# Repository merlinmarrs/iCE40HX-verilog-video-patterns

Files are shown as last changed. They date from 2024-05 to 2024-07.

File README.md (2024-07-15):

bechamel_logo_Plan de travail 1

# Video FPGA Dev Board

A Lattice iCE40HX1K-based FPGA developement board for live-playable video experiments.



 

|                          |                          |
:-------------------------:|:-------------------------:
  | IMG_3808-1024x683

# Features :

- 9-key mechanical button interface
- Relatively low-cost, single board design
- HDMI and VGA out
- Reverse polarity and fuse protection

# Minimal BOM :

[Excel BOM Mouser / Digikey ](https://github.com/merlinmarrs/iCE40HX-verilog-video-patterns/tree/main/PCB%20files)

- 9x Mechanical keyboard keys
- 1x FPGA iCE40HX1K-TQ144
- 1x 100MHz clock oscillator
- 1x SRAM 2Mb 256Kx8
- 1x Flash N25Q032A13ESC40F
- 1x USB-C SMD 6 pin connector
- 1x 3.3V reg TLV73333PDBVT 
- 1x 1.2V reg TLV73312PDBVT
- 1x PFET
- 1x Resettable Fuse
- 1x D-SUB 15 connector
- 1x HDMI Connector 
- 50x 0.1µF capacitor 0805
- 50x  10kΩ, 1.8kΩ, 1kΩ, 470Ω, 270Ω, 120Ω resistors 0805
- 5x LEDs 0805
- 2x Dual-row headers

optional extras : (1x Raspberry Pi Zero, 1x Micro SD holder, 2x 10kΩ potentiometers, 1x fast op-amp, 1x 3.5mm audio jack, 1x dual SMD dip switch, 1x SMD pushbutton)

# PCB files

[KiCAD and Eagle PCBs](https://github.com/merlinmarrs/iCE40HX-verilog-video-patterns/tree/main/PCB%20files)

open_source 

# HDL files

[Verilog, Pin constraints, and synthesized binaries ](https://github.com/merlinmarrs/iCE40HX-verilog-video-patterns/tree/main/verilog)

To compile and upload files :

[Yoysis Open-source Toolchain ](https://github.com/YosysHQ/yosys)



[iCEcube2 Toolchain](https://www.latticesemi.com/iCEcube2)



## Acknowledgements

Mike Field <hamster@snap.net.nz> for his minimalDVID_encoder.vhd : A quick and dirty DVI-D implementation

OLIMEX FPGA dev board https://github.com/OLIMEX/iCE40HX1K-EVB/tree/master

ALHAMBRA FPGA https://github.com/FPGAwars/Alhambra-II-FPGA/tree/master

HDL Bits https://hdlbits.01xz.net/wiki/Main_Page

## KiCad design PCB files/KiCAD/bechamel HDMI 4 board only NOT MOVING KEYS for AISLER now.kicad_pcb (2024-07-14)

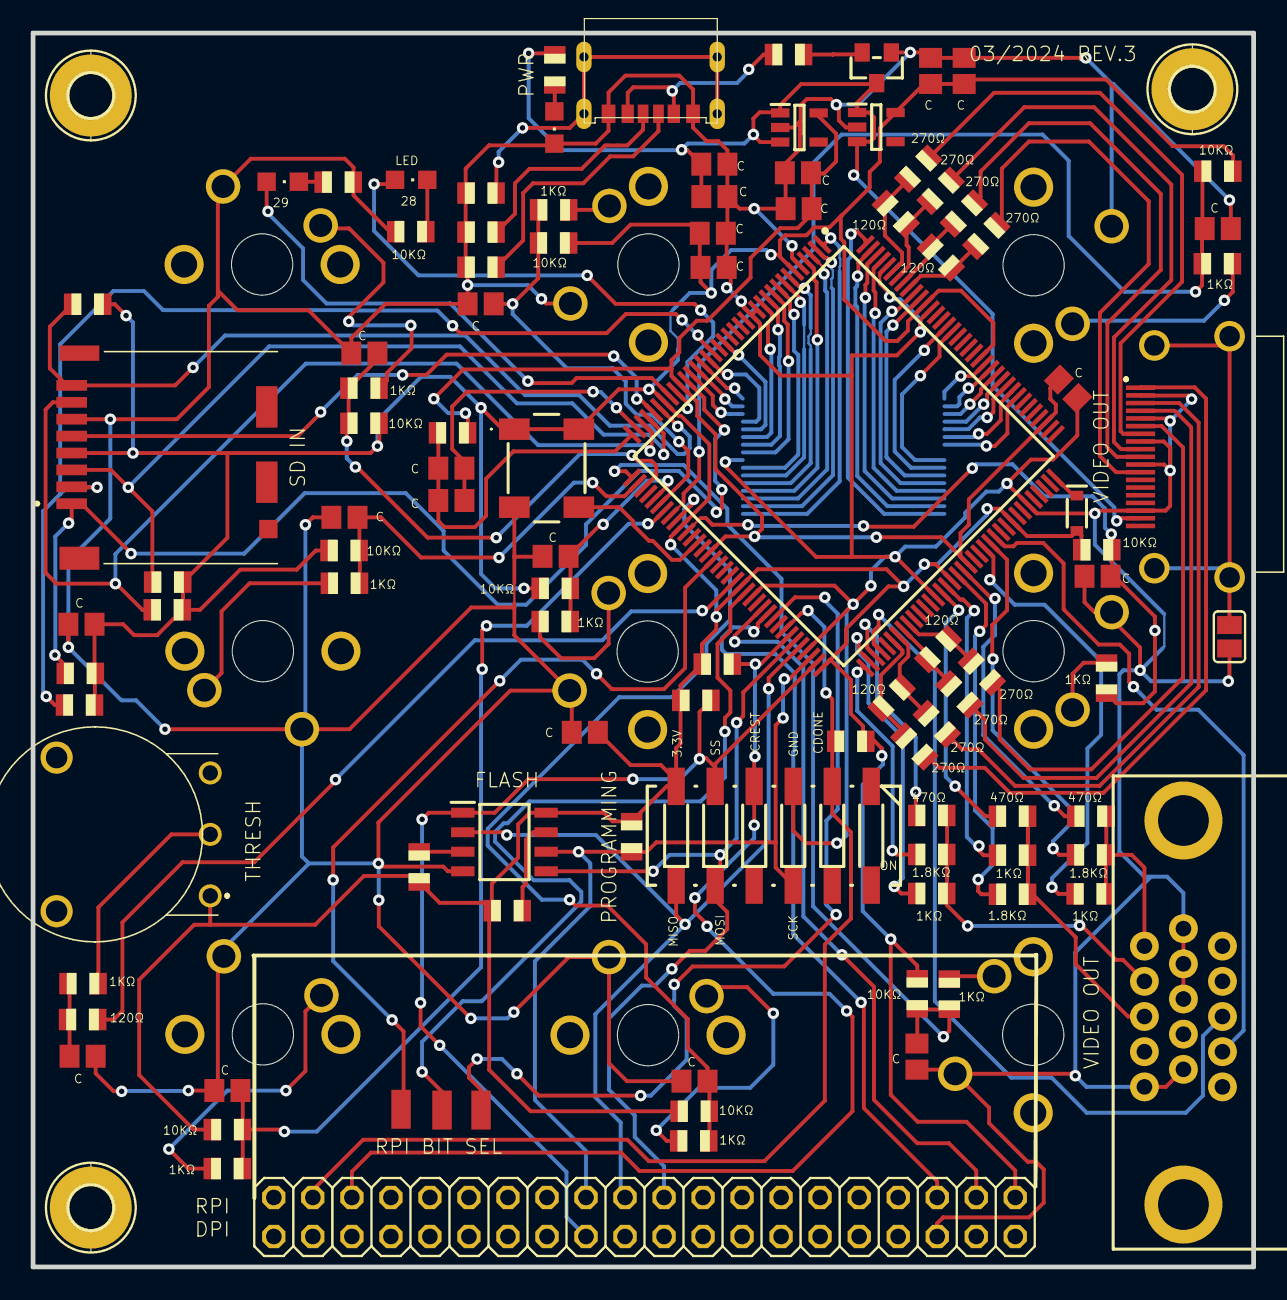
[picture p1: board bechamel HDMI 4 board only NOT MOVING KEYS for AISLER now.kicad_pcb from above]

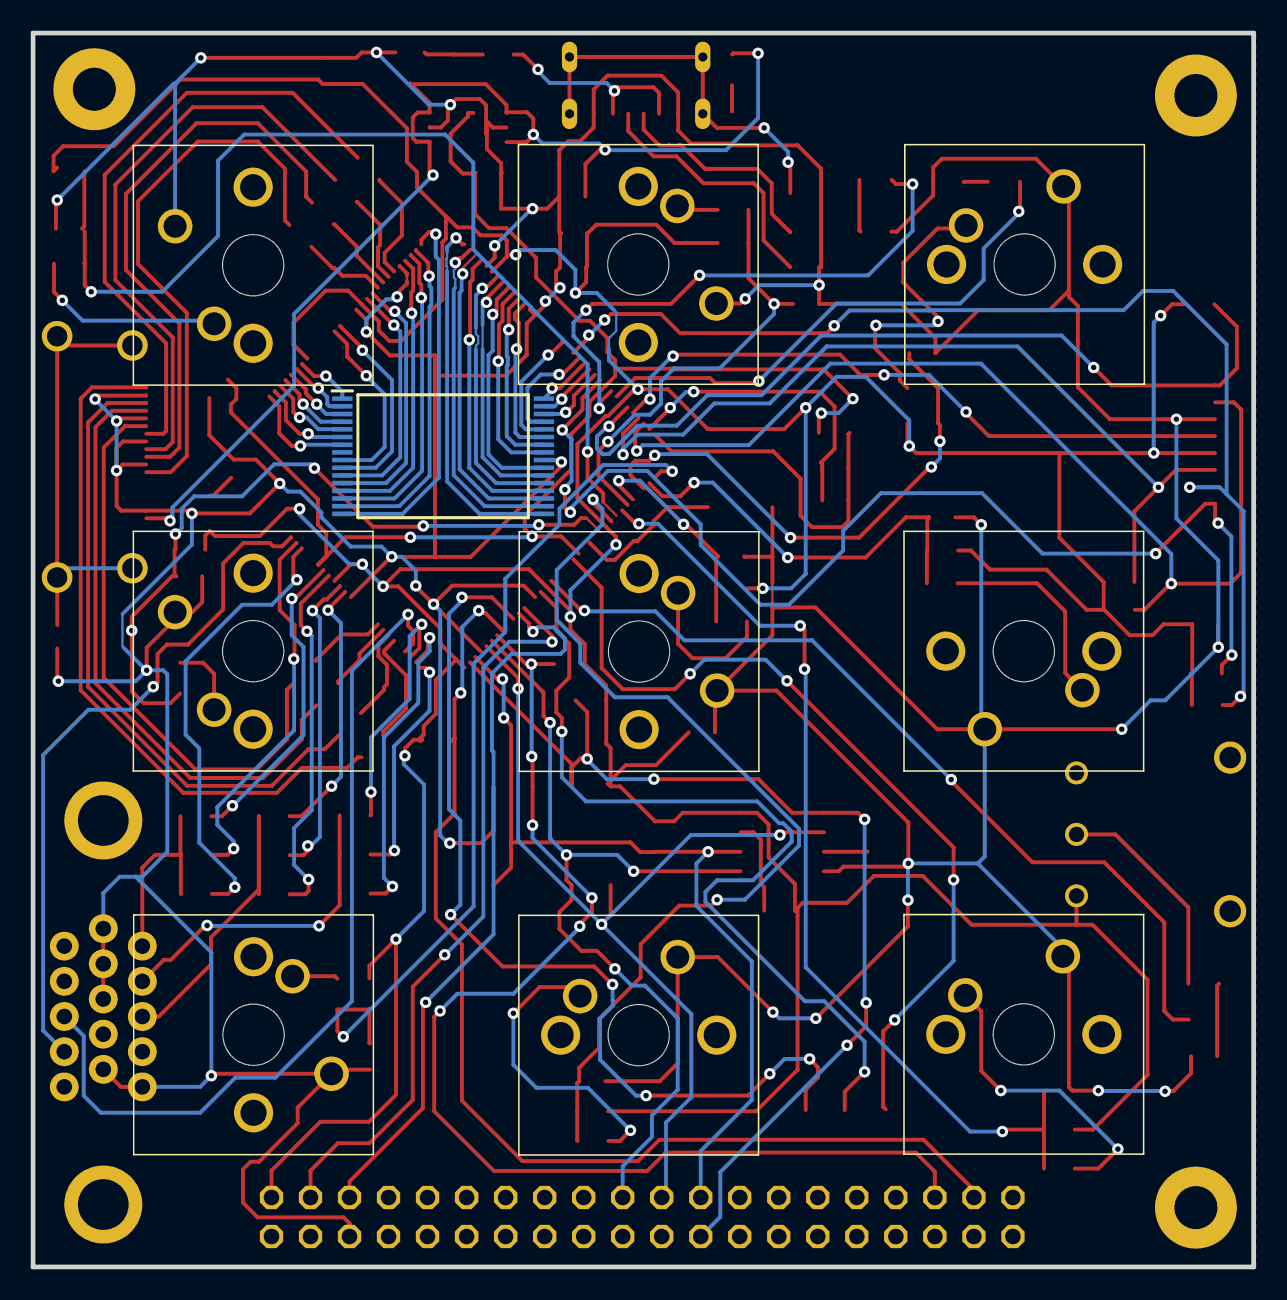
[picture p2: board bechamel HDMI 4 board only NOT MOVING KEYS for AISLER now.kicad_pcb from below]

Board: 2 copper layers, 79.5 x 80.3 mm, 117 parts (10 on the bottom side), 119 nets.

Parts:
C1, C6, C7, C8, C9, C10, C11, C12, C13, C14, C15, C18, C21, C22, C25, C26, C27: 0.1uF; C0805
C3, C4, C5, C16, C23: 10uF; C0805
C17: 5.6nF; C0805
D1: 250mA/100V; SOD-323
FUSE0: FUSE; R0805
H1, H5, H6: MOUNT-PAD-ROUND2.8; 2,8-PAD
IC1: TLV73333PDBVT; SOT95P280X145-5N
IC2: ICE40HX1K-TQ144; QFP50P2200X2200X160-144N
IC3: TLV73312PDBVT; SOT95P280X145-5N
IC4: N25Q032A13ESC40F; SOIC127P600X175-8N
IC6: IS62WV2568BLL-55HLI; SOP50P1340X125-32N
J2: SS-53000-001; SS53000001
J3: DM3CS-SF; DM3CSSF
JP1: 2X20
LED6, LED12, LED13: CHIPLED_0805
P-FET2: SOT23-WIDE
PAD1, PAD2, PAD3: SMD1,27-2,54
R1, R17, R25: 470R; R0805
R2, R5, R7, R15, R18, R22, R24, R26, R47, R49, R51, R53: 1K; R0805
R3, R4, R6, R8, R9, R10, R11, R12, R13, R21, R23, R45, R46, R48, R50, R52, R54, R55, R58, R59: 10K; R0805
R14, R36, R37: 100 ohm; R0805
R16, R20, R27: 1.8K; R0805
R19: 300 ohm; R0805
R28, R29, R31, R32, R34, R35, R39, R40: 270R; R0805
R30, R33, R38, R41: 120R; R0805
R42: 1M; R0805
R43, R44: 5k1; R0805
R56: 1K8 ohm; R0805
R57: 180 ohm; R0805
S1, S2, S3, S4, S5, S6, S7, S8, S13: MX1A-11NW; MX1A11NW
S9: 219-06J; CTS-219-06J
SJ2: SJ
U$1: DB15
U$2: USBC-6P; USCX-06FX-XXMX-01
VR1: RV100F-30-4K1B-B10K-B301; RV100F304K1BB10KB301
Y2: ECS-3953M-080-BN-T-TR; ECS3953M080BNTTR

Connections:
1.2V: C4.1, C26.1, C27.1, IC2.27, IC2.51, IC2.92, IC2.111, IC3.5, R14.2
3.3V: C12.1, C15.1, C16.2, C18.1, C21.1, C25.1, D1.A, IC1.5, IC2.6, IC2.30, IC2.46, IC2.57, IC2.72, IC2.89, IC2.100, IC2.123, IC2.133, IC4.8, J3.4, JP1.1, R3.2, R4.2, R6.2, R8.2, R9.2, R10.2, R11.2, R12.2, R13.2, R21.2, R23.2, R45.2, R46.2, R48.2, R50.2, R52.2, R54.2, R55.1, R58.2, R59.2, S9.6, VR1.1, Y2.1, Y2.4
5V: C3.1, C5.1, IC1.1, IC1.3, IC3.1, IC3.3, J2.18, P-FET2.3, R19.2
5V?: FUSE0.1, P-FET2.2
A0: IC2.4, IC6.20
A1: IC2.3, IC6.19
A2: IC2.2, IC6.18
A3: IC2.1, IC6.17
A4: IC2.144, IC6.16
A5: IC2.143, IC6.15
A6: IC2.142, IC6.14
A7: IC2.141, IC6.13
A8: IC2.120, IC6.3
A9: IC2.121, IC6.2
A10: IC2.24, IC6.31
A11: IC2.122, IC6.1
A12: IC2.135, IC6.12
A13: IC2.119, IC6.4
A14: IC2.134, IC6.11
A15: IC2.116, IC6.7
A16: IC2.129, IC6.10
A17: IC2.128, IC6.9
ADC_IN: IC2.56, R57.2
BLUE: R1.2, R15.2, R16.2, U$1.3
BLUE_1: IC2.87, R1.1
BLUE_2: IC2.88, R15.1
BLUE_3: IC2.90, R16.1
CLK+: IC2.137, R39.2, R41.1
CLK-: IC2.136, R40.2, R41.2
CMD: IC2.33, J3.3, R54.1
CS2: IC2.117, IC6.6
DAT0: IC2.34, J3.7, R55.2
DAT1: IC2.31, J3.8, R59.1
DAT2: IC2.26, J3.1, R45.1
DAT3: IC2.21, J3.2, R58.1
DATA0+: IC2.139, R34.2, R38.1
DATA0-: IC2.138, R35.2, R38.2
DATA1+: IC2.80, R31.2, R33.1
DATA1-: IC2.81, R32.2, R33.2
DATA2+: IC2.78, R28.2, R30.1
DATA2-: IC2.79, R29.2, R30.2
FPGA_CLK: IC2.49, Y2.3
GND: C1.1, C3.2, C4.2, C5.2, C6.1, C7.1, C8.1, C9.1, C10.1, C11.1, C12.2, C13.1, C14.1, C15.2, C16.1, C17.1, C18.2, C21.2, C25.2, C26.2, C27.2, IC1.2, IC2.5, IC2.13, IC2.14, IC2.59, IC2.69, IC2.86, IC2.103, IC2.132, IC2.140, IC3.2, IC4.4, IC6.24, J2.2, J2.5, J2.8, J2.11, J2.17, J3.6, JP1.6, LED6.C, P-FET2.1, R36.1, R37.1, R42.2, R43.2, R44.2, S1.2, S2.2, S3.2, S4.2, S5.2, S6.2, S7.2, S8.2, S9.3, S13.2, SJ2.2, U$1.5, U$1.6, U$1.7, U$1.8, U$1.10, U$2.GND1, U$2.GND2, Y2.2
GREEN: R17.2, R18.2, R20.2, U$1.2
GREEN_1: IC2.75, R17.1
GREEN_2: IC2.74, R18.1
GREEN_3: IC2.73, R20.1
H_SYNC: IC2.76, U$1.13
H_SYNC_IN: IC2.62, JP1.5
I/O0: IC2.7, IC6.21
I/O1: IC2.8, IC6.22
I/O2: IC2.9, IC6.23
I/O3: IC2.10, IC6.25
I/O4: IC2.11, IC6.26
I/O5: IC2.12, IC6.27
I/O6: IC2.19, IC6.28
I/O7: IC2.22, IC6.29
ICE_CDONE: IC2.65, JP1.37, R8.1, S9.2
ICE_CREST: IC2.66, JP1.35, R9.1, S9.4
ICE_MISO: IC2.68, IC4.2, JP1.21, S9.7
ICE_MOSI: IC2.67, IC4.5, JP1.19, S9.8
ICE_SCK: IC2.70, IC4.6, JP1.23, R13.1, S9.10
ICE_SS_B: IC2.71, IC4.1, JP1.24, R12.1, S9.5
KEY_0: C13.2, IC2.37, R50.1, R51.2
KEY_0_LED: IC2.28, LED12.A
KEY_1: C6.2, IC2.38, R3.1, R5.2
KEY_1_LED: IC2.29, LED13.A
KEY_2: C11.2, IC2.39, R48.1, R49.2
KEY_3: C1.2, IC2.41, R2.2, R4.1
KEY_4: C10.2, IC2.42, R46.1, R47.2
KEY_5: C7.2, IC2.43, R6.1, R7.2
KEY_6: C9.2, IC2.44, R23.1, R24.2
KEY_7: C8.2, IC2.45, R21.1, R22.2
KEY_8: C14.2, IC2.47, R52.1, R53.2
unnamed: IC4.7, R10.1
unnamed: LED6.A, R19.1
unnamed: IC4.3, R11.1
unnamed: R43.1, U$2.CC2
unnamed: D1.C, IC2.108
unnamed: C22.2, C23.2, IC2.35
unnamed: C22.1, C23.1, IC2.36, R14.1
unnamed: R42.1, U$2.SHIELD1, U$2.SHIELD2, U$2.SHIELD3, U$2.SHIELD4
unnamed: R56.2, VR1.2
unnamed: J2.1, R28.1
unnamed: R44.1, U$2.CC1
unnamed: J2.MH1, J2.MH2, J2.MH3, J2.MH4, SJ2.1
unnamed: C17.2, R56.1, R57.1
unnamed: J2.3, R29.1
unnamed: J2.4, R31.1
unnamed: LED12.C, R36.2
unnamed: LED13.C, R37.2
unnamed: J2.6, R32.1
unnamed: IC2.52, PAD1.1
unnamed: J2.7, R34.1
unnamed: J2.9, R35.1
unnamed: J2.10, R39.1
unnamed: J2.12, R40.1
unnamed: R2.1, S6.1
unnamed: R5.1, S5.1
unnamed: R7.1, S7.1
unnamed: R22.1, S8.1
unnamed: R24.1, S3.1
unnamed: R47.1, S2.1
unnamed: R49.1, S1.1
unnamed: R51.1, S13.1
unnamed: R53.1, S4.1
unnamed: IC2.58, PAD2.1
unnamed: IC2.63, PAD3.1
PRE_FUSE: FUSE0.2, U$2.VBUS1, U$2.VBUS2
RED: R25.2, R26.2, R27.2, U$1.1
RED_1: IC2.91, R25.1
RED_2: IC2.95, R26.1
RED_3: IC2.96, R27.1
SD_CLK: IC2.32, J3.5
V_SYNC: IC2.97, U$1.14
V_SYNC_IN: IC2.61, JP1.3
~CS1: IC2.25, IC6.30
~OE: IC2.23, IC6.32
~WE: IC2.118, IC6.5

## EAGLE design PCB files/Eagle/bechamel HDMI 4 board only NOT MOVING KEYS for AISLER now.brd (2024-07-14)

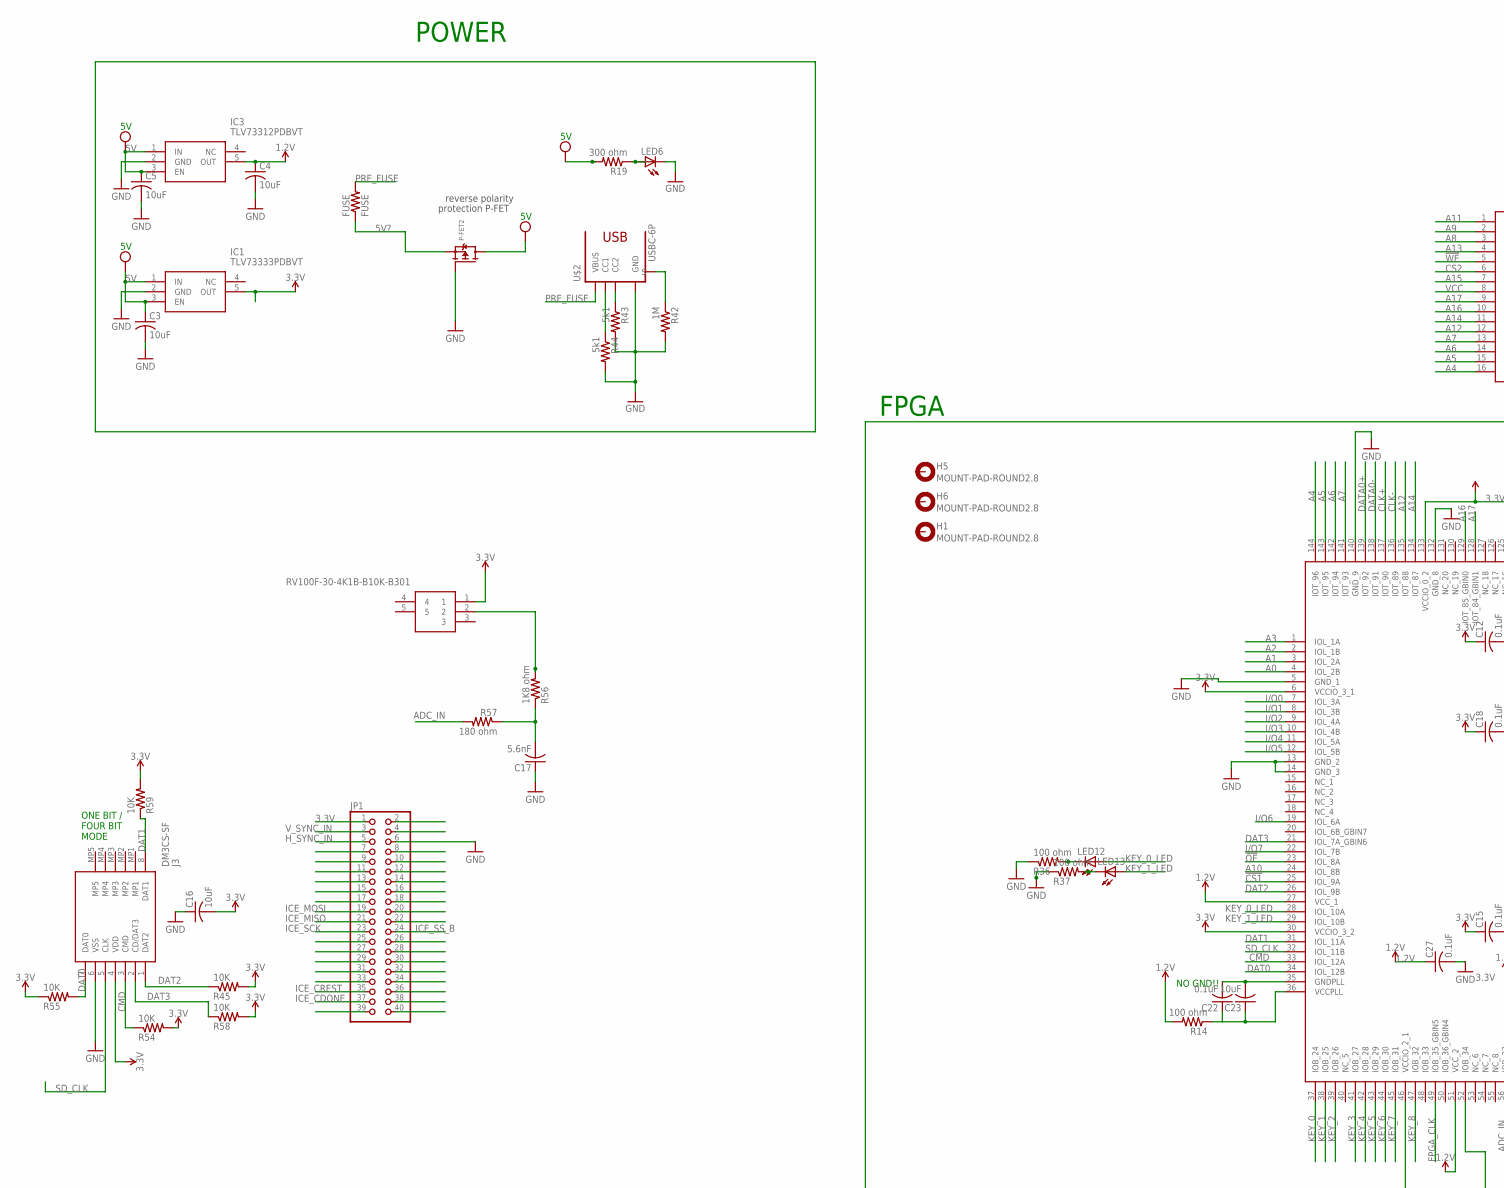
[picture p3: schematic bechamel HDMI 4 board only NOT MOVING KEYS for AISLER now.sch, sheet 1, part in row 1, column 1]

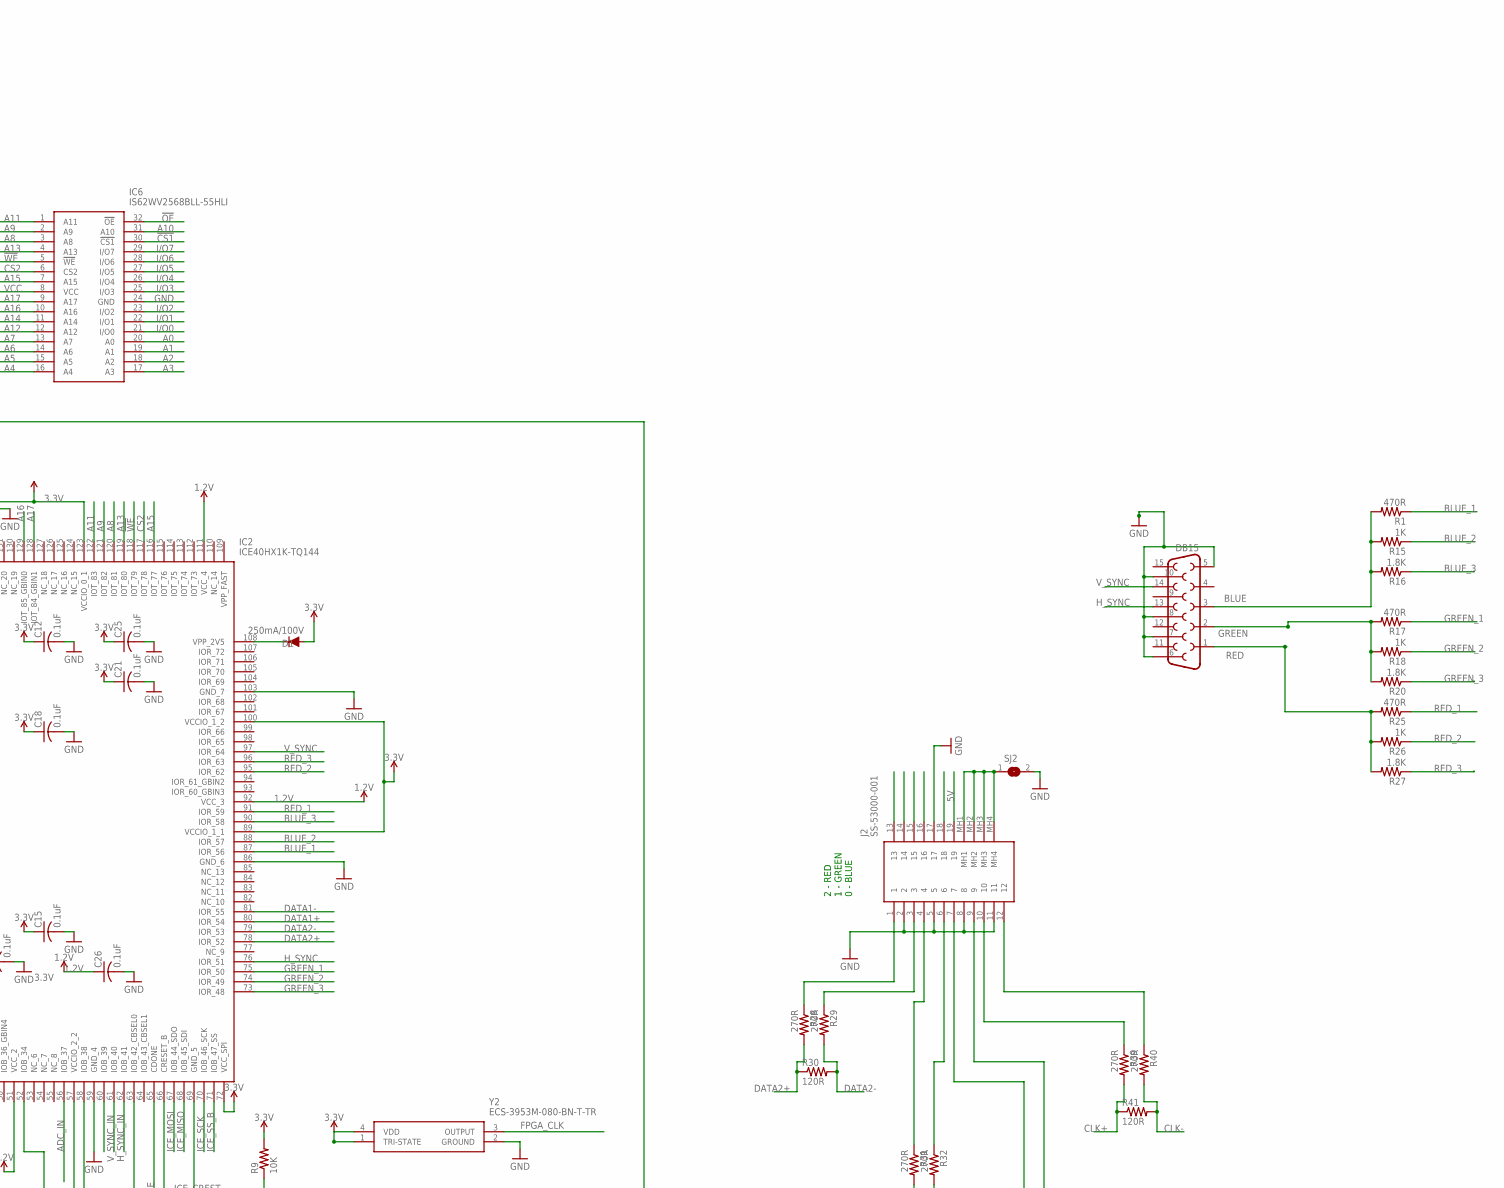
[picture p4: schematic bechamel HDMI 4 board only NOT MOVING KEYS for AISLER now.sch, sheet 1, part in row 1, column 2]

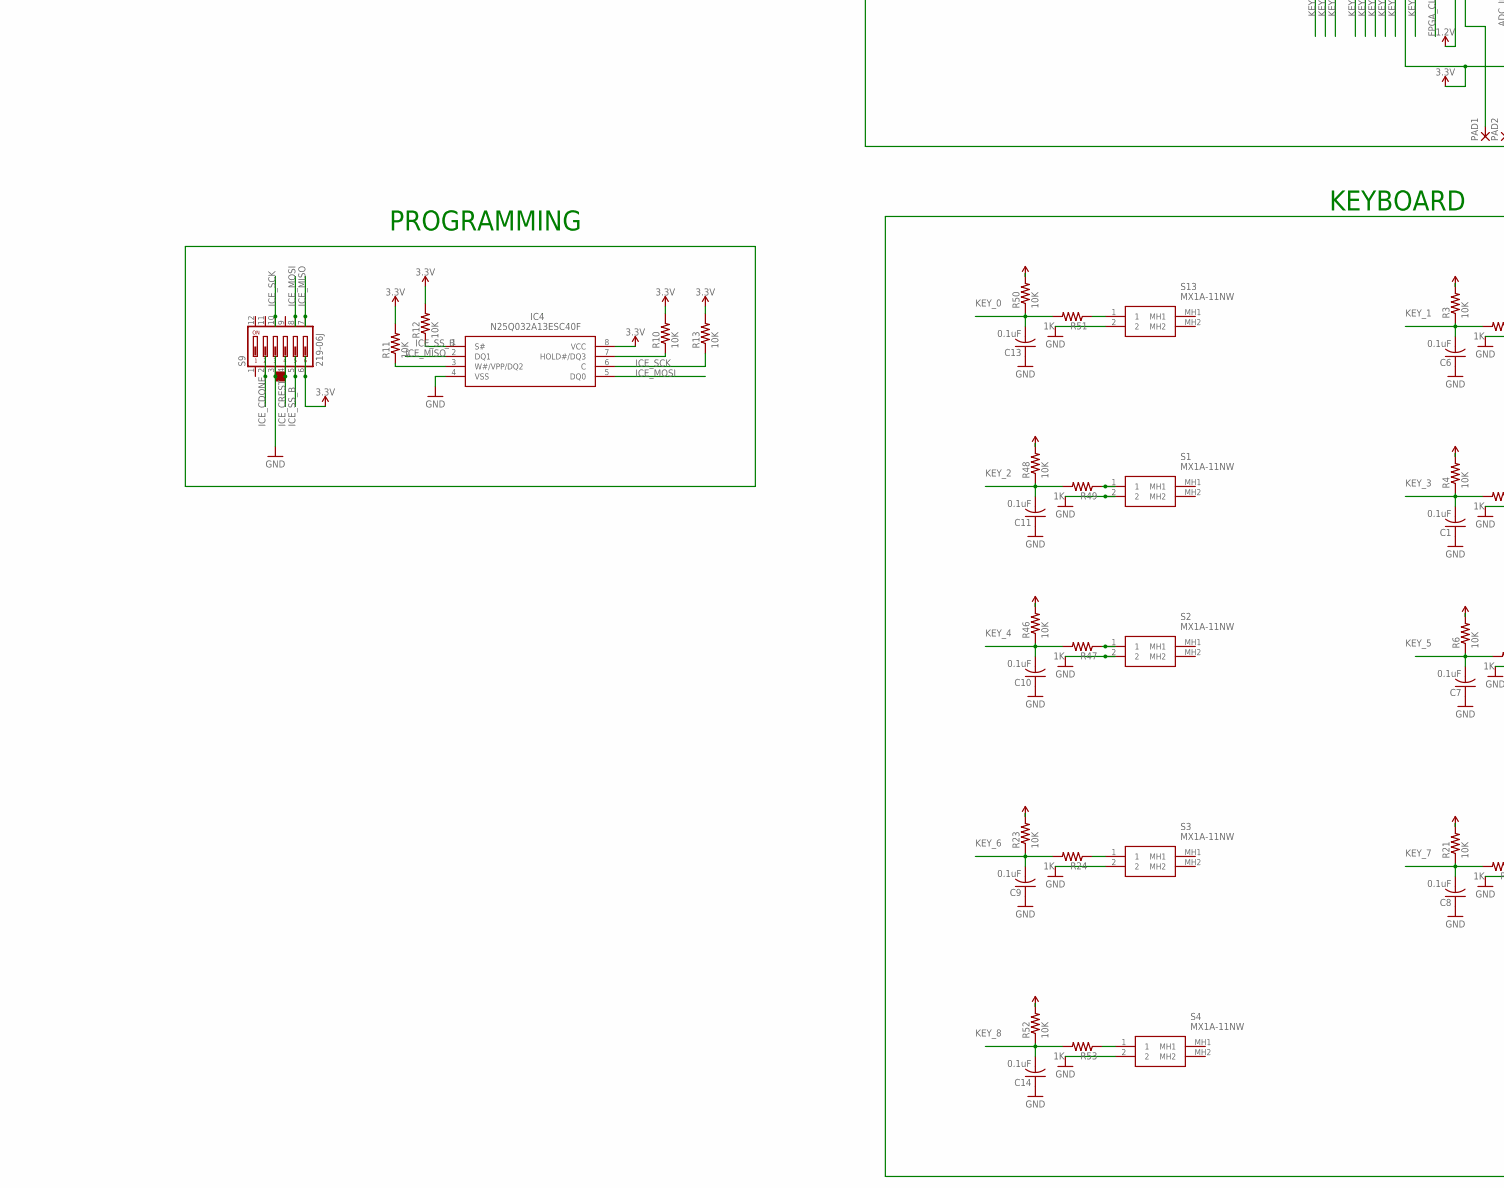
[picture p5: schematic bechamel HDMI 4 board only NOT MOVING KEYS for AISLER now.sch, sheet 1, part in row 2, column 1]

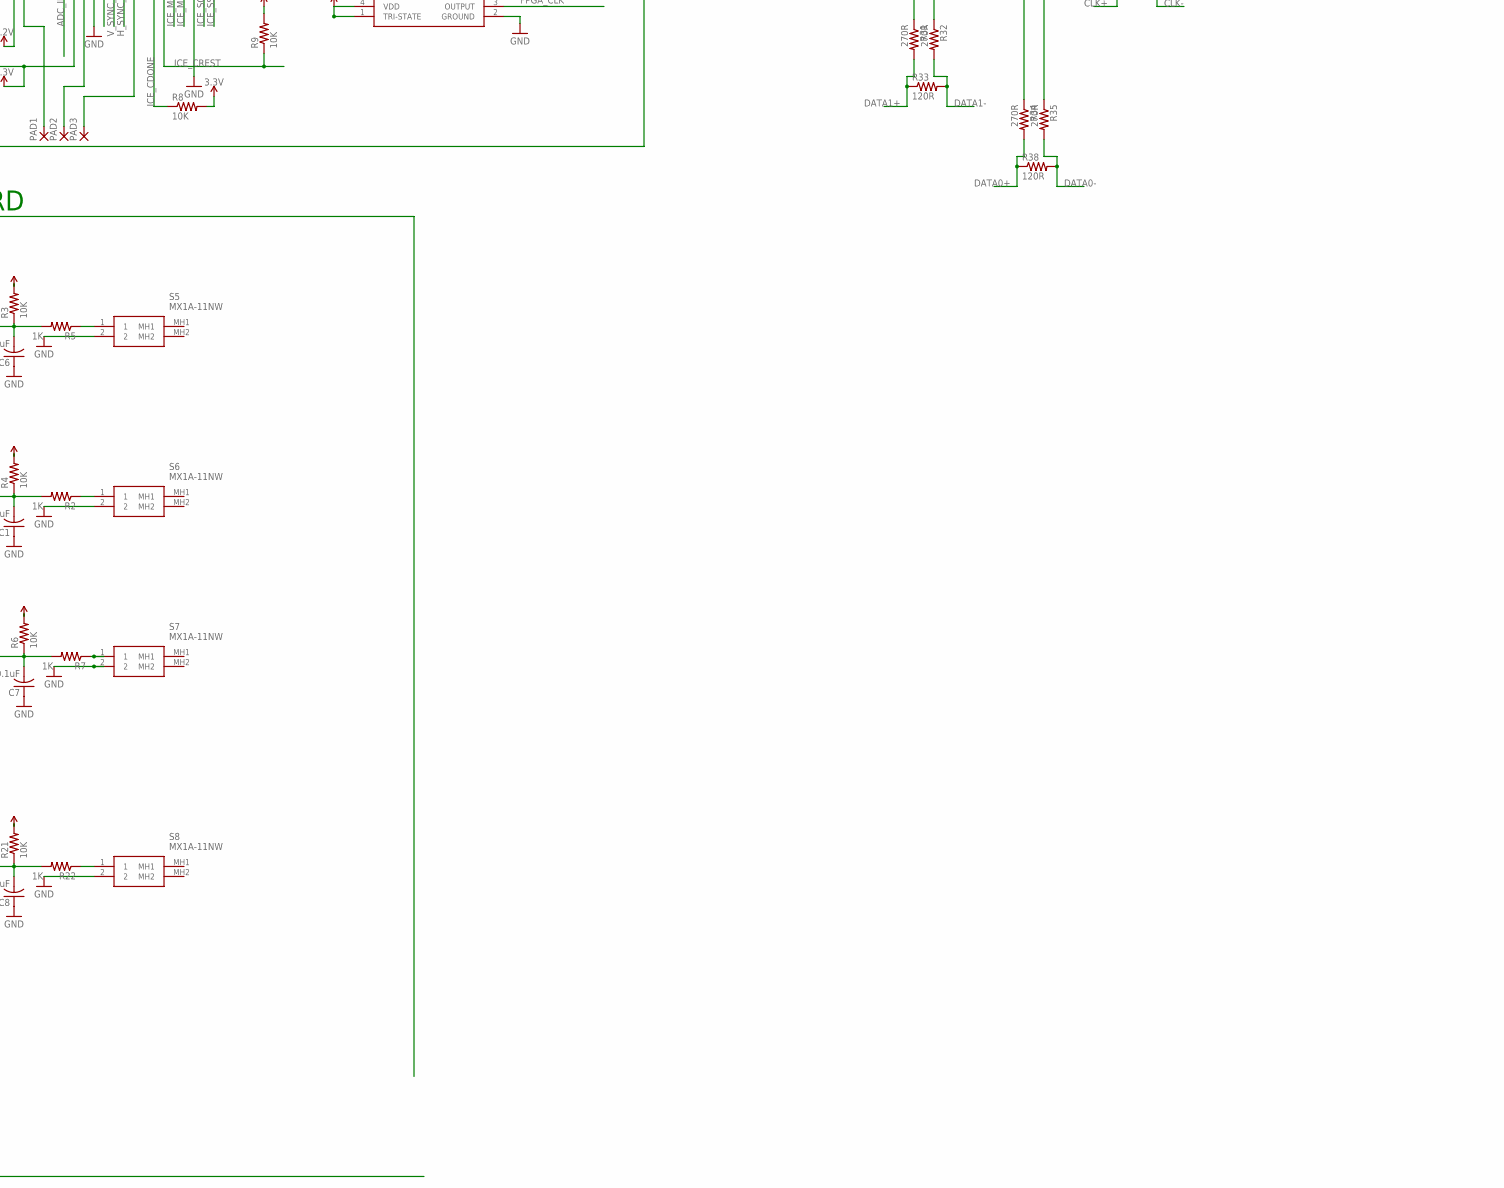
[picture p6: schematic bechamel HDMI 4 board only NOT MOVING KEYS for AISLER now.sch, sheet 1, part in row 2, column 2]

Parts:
C1, C6, C7, C8, C9, C10, C11, C12, C13, C14, C15, C18, C21, C22, C25, C26, C27: 0.1uF; C0805
C3, C4, C5, C16, C23: 10uF; C0805
C17: 5.6nF; C0805
D1: 250mA/100V; SOD-323
FUSE: FUSE; R0805
H1, H5, H6: MOUNT-PAD-ROUND2.8; 2,8-PAD
IC1: TLV73333PDBVT; SOT95P280X145-5N
IC2: ICE40HX1K-TQ144; QFP50P2200X2200X160-144N
IC3: TLV73312PDBVT; SOT95P280X145-5N
IC4: N25Q032A13ESC40F; SOIC127P600X175-8N
IC6: IS62WV2568BLL-55HLI; SOP50P1340X125-32N
J2: SS-53000-001; SS53000001
J3: DM3CS-SF; DM3CSSF
JP1: PINHD-2X20; 2X20
LED6, LED12, LED13: LEDCHIPLED_0805; CHIPLED_0805
P-FET2: MOSFET-PWIDE; SOT23-WIDE
PAD1, PAD2, PAD3: SMD2; SMD1,27-2,54
R1, R17, R25: 470R; R0805
R2, R5, R7, R15, R18, R22, R24, R26, R47, R49, R51, R53: 1K; R0805
R3, R4, R6, R8, R9, R10, R11, R12, R13, R21, R23, R45, R46, R48, R50, R52, R54, R55, R58, R59: 10K; R0805
R14, R36, R37: 100 ohm; R0805
R16, R20, R27: 1.8K; R0805
R19: 300 ohm; R0805
R28, R29, R31, R32, R34, R35, R39, R40: 270R; R0805
R30, R33, R38, R41: 120R; R0805
R42: 1M; R0805
R43, R44: 5k1; R0805
R56: 1K8 ohm; R0805
R57: 180 ohm; R0805
S1, S2, S3, S4, S5, S6, S7, S8, S13: MX1A-11NW; MX1A11NW
S9: 219-06J; CTS-219-06J
SJ2: SJ
U$1: DB15
U$2: USBC-6P; USCX-06FX-XXMX-01
VR1: RV100F-30-4K1B-B10K-B301; RV100F304K1BB10KB301
Y2: ECS-3953M-080-BN-T-TR; ECS3953M080BNTTR

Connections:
1.2V: C4.1, C26.1, C27.1, IC2.27 (VCC_1), IC2.51 (VCC_2), IC2.92 (VCC_3), IC2.111 (VCC_4), IC3.5 (OUT), R14.2
3.3V: C12.1, C15.1, C16.2, C18.1, C21.1, C25.1, D1.A, IC1.5 (OUT), IC2.6 (VCCIO_3_1), IC2.30 (VCCIO_3_2), IC2.46 (VCCIO_2_1), IC2.57 (VCCIO_2_2), IC2.72 (VCC_SPI), IC2.89 (VCCIO_1_1), IC2.100 (VCCIO_1_2), IC2.123 (VCCIO_0_1), IC2.133 (VCCIO_0_2), IC4.8 (VCC), J3.4 (VDD), JP1.1, R3.2, R4.2, R6.2, R8.2, R9.2, R10.2, R11.2, R12.2, R13.2, R21.2, R23.2, R45.2, R46.2, R48.2, R50.2, R52.2, R54.2, R55.1, R58.2, R59.2, S9.6, VR1.1, Y2.1 (TRI-STATE), Y2.4 (VDD)
5V: C3.1, C5.1, IC1.1 (IN), IC1.3 (EN), IC3.1 (IN), IC3.3 (EN), J2.18, P-FET2.3 (D), R19.2
5V?: FUSE.1, P-FET2.2 (S)
!CS1: IC2.25 (IOL_9A), IC6.30 (!CS1)
!OE: IC2.23 (IOL_8A), IC6.32 (!OE)
!WE: IC2.118 (IOT_79), IC6.5 (!WE)
A0: IC2.4 (IOL_2B), IC6.20 (A0)
A1: IC2.3 (IOL_2A), IC6.19 (A1)
A2: IC2.2 (IOL_1B), IC6.18 (A2)
A3: IC2.1 (IOL_1A), IC6.17 (A3)
A4: IC2.144 (IOT_96), IC6.16 (A4)
A5: IC2.143 (IOT_95), IC6.15 (A5)
A6: IC2.142 (IOT_94), IC6.14 (A6)
A7: IC2.141 (IOT_93), IC6.13 (A7)
A8: IC2.120 (IOT_81), IC6.3 (A8)
A9: IC2.121 (IOT_82), IC6.2 (A9)
A10: IC2.24 (IOL_8B), IC6.31 (A10)
A11: IC2.122 (IOT_83), IC6.1 (A11)
A12: IC2.135 (IOT_88), IC6.12 (A12)
A13: IC2.119 (IOT_80), IC6.4 (A13)
A14: IC2.134 (IOT_87), IC6.11 (A14)
A15: IC2.116 (IOT_77), IC6.7 (A15)
A16: IC2.129 (IOT_85_GBIN0), IC6.10 (A16)
A17: IC2.128 (IOT_84_GBIN1), IC6.9 (A17)
ADC_IN: IC2.56 (IOB_37), R57.2
BLUE: R1.2, R15.2, R16.2, U$1.3
BLUE_1: IC2.87 (IOR_56), R1.1
BLUE_2: IC2.88 (IOR_57), R15.1
BLUE_3: IC2.90 (IOR_58), R16.1
CLK+: IC2.137 (IOT_90), R39.2, R41.1
CLK-: IC2.136 (IOT_89), R40.2, R41.2
CMD: IC2.33 (IOL_12A), J3.3 (CMD), R54.1
CS2: IC2.117 (IOT_78), IC6.6 (CS2)
DAT0: IC2.34 (IOL_12B), J3.7 (DAT0), R55.2
DAT1: IC2.31 (IOL_11A), J3.8 (DAT1), R59.1
DAT2: IC2.26 (IOL_9B), J3.1 (DAT2), R45.1
DAT3: IC2.21 (IOL_7A_GBIN6), J3.2 (CD/DAT3), R58.1
DATA0+: IC2.139 (IOT_92), R34.2, R38.1
DATA0-: IC2.138 (IOT_91), R35.2, R38.2
DATA1+: IC2.80 (IOR_54), R31.2, R33.1
DATA1-: IC2.81 (IOR_55), R32.2, R33.2
DATA2+: IC2.78 (IOR_52), R28.2, R30.1
DATA2-: IC2.79 (IOR_53), R29.2, R30.2
FPGA_CLK: IC2.49 (IOB_35_GBIN5), Y2.3 (OUTPUT)
GND: C1.1, C3.2, C4.2, C5.2, C6.1, C7.1, C8.1, C9.1, C10.1, C11.1, C12.2, C13.1, C14.1, C15.2, C16.1, C17.1, C18.2, C21.2, C25.2, C26.2, C27.2, IC1.2 (GND), IC2.5 (GND_1), IC2.13 (GND_2), IC2.14 (GND_3), IC2.59 (GND_4), IC2.69 (GND_5), IC2.86 (GND_6), IC2.103 (GND_7), IC2.132 (GND_8), IC2.140 (GND_9), IC3.2 (GND), IC4.4 (VSS), IC6.24 (GND), J2.2, J2.5, J2.8, J2.11, J2.17, J3.6 (VSS), JP1.6, LED6.C, P-FET2.1 (G), R36.1, R37.1, R42.2, R43.2, R44.2, S1.2, S2.2, S3.2, S4.2, S5.2, S6.2, S7.2, S8.2, S9.3, S13.2, SJ2.2, U$1.5, U$1.6, U$1.7, U$1.8, U$1.10, U$2.GND1 (GND), U$2.GND2 (GND), Y2.2 (GROUND)
GREEN: R17.2, R18.2, R20.2, U$1.2
GREEN_1: IC2.75 (IOR_50), R17.1
GREEN_2: IC2.74 (IOR_49), R18.1
GREEN_3: IC2.73 (IOR_48), R20.1
H_SYNC: IC2.76 (IOR_51), U$1.13
H_SYNC_IN: IC2.62 (IOB_41), JP1.5
I/O0: IC2.7 (IOL_3A), IC6.21 (I/O0)
I/O1: IC2.8 (IOL_3B), IC6.22 (I/O1)
I/O2: IC2.9 (IOL_4A), IC6.23 (I/O2)
I/O3: IC2.10 (IOL_4B), IC6.25 (I/O3)
I/O4: IC2.11 (IOL_5A), IC6.26 (I/O4)
I/O5: IC2.12 (IOL_5B), IC6.27 (I/O5)
I/O6: IC2.19 (IOL_6A), IC6.28 (I/O6)
I/O7: IC2.22 (IOL_7B), IC6.29 (I/O7)
ICE_CDONE: IC2.65 (CDONE), JP1.37, R8.1, S9.2
ICE_CREST: IC2.66 (CRESET_B), JP1.35, R9.1, S9.4
ICE_MISO: IC2.68 (IOB_45_SDI), IC4.2 (DQ1), JP1.21, S9.7
ICE_MOSI: IC2.67 (IOB_44_SDO), IC4.5 (DQ0), JP1.19, S9.8
ICE_SCK: IC2.70 (IOB_46_SCK), IC4.6 (C), JP1.23, R13.1, S9.10
ICE_SS_B: IC2.71 (IOB_47_SS), IC4.1 (S#), JP1.24, R12.1, S9.5
KEY_0: C13.2, IC2.37 (IOB_24), R50.1, R51.2
KEY_0_LED: IC2.28 (IOL_10A), LED12.A
KEY_1: C6.2, IC2.38 (IOB_25), R3.1, R5.2
KEY_1_LED: IC2.29 (IOL_10B), LED13.A
KEY_2: C11.2, IC2.39 (IOB_26), R48.1, R49.2
KEY_3: C1.2, IC2.41 (IOB_27), R2.2, R4.1
KEY_4: C10.2, IC2.42 (IOB_28), R46.1, R47.2
KEY_5: C7.2, IC2.43 (IOB_29), R6.1, R7.2
KEY_6: C9.2, IC2.44 (IOB_30), R23.1, R24.2
KEY_7: C8.2, IC2.45 (IOB_31), R21.1, R22.2
KEY_8: C14.2, IC2.47 (IOB_32), R52.1, R53.2
unnamed: IC4.7 (HOLD#/DQ3), R10.1
unnamed: LED6.A, R19.1
unnamed: IC4.3 (W#/VPP/DQ2), R11.1
unnamed: R43.1, U$2.CC2
unnamed: D1.C, IC2.108 (VPP_2V5)
unnamed: C22.2, C23.2, IC2.35 (GNDPLL)
unnamed: C22.1, C23.1, IC2.36 (VCCPLL), R14.1
unnamed: R42.1, U$2.SHIELD1 (S), U$2.SHIELD2 (S), U$2.SHIELD3 (S), U$2.SHIELD4 (S)
unnamed: R56.2, VR1.2
unnamed: J2.1, R28.1
unnamed: R44.1, U$2.CC1
unnamed: J2.MH1, J2.MH2, J2.MH3, J2.MH4, SJ2.1
unnamed: C17.2, R56.1, R57.1
unnamed: J2.3, R29.1
unnamed: J2.4, R31.1
unnamed: LED12.C, R36.2
unnamed: LED13.C, R37.2
unnamed: J2.6, R32.1
unnamed: IC2.52 (IOB_34), PAD1.1
unnamed: J2.7, R34.1
unnamed: J2.9, R35.1
unnamed: J2.10, R39.1
unnamed: J2.12, R40.1
unnamed: R2.1, S6.1
unnamed: R5.1, S5.1
unnamed: R7.1, S7.1
unnamed: R22.1, S8.1
unnamed: R24.1, S3.1
unnamed: R47.1, S2.1
unnamed: R49.1, S1.1
unnamed: R51.1, S13.1
unnamed: R53.1, S4.1
unnamed: IC2.58 (IOB_38), PAD2.1
unnamed: IC2.63 (IOB_42_CBSEL0), PAD3.1
PRE_FUSE: FUSE.2, U$2.VBUS1 (VBUS), U$2.VBUS2 (VBUS)
RED: R25.2, R26.2, R27.2, U$1.1
RED_1: IC2.91 (IOR_59), R25.1
RED_2: IC2.95 (IOR_62), R26.1
RED_3: IC2.96 (IOR_63), R27.1
SD_CLK: IC2.32 (IOL_11B), J3.5 (CLK)
VCC: IC6.8 (VCC)
V_SYNC: IC2.97 (IOR_64), U$1.14
V_SYNC_IN: IC2.61 (IOB_40), JP1.3

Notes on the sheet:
NO GND!!
POWER
reverse polarity
protection P-FET
PROGRAMMING
FPGA
KEYBOARD
2 - RED 1 - GREEN 0 - BLUE
ONE BIT / FOUR BIT MODE

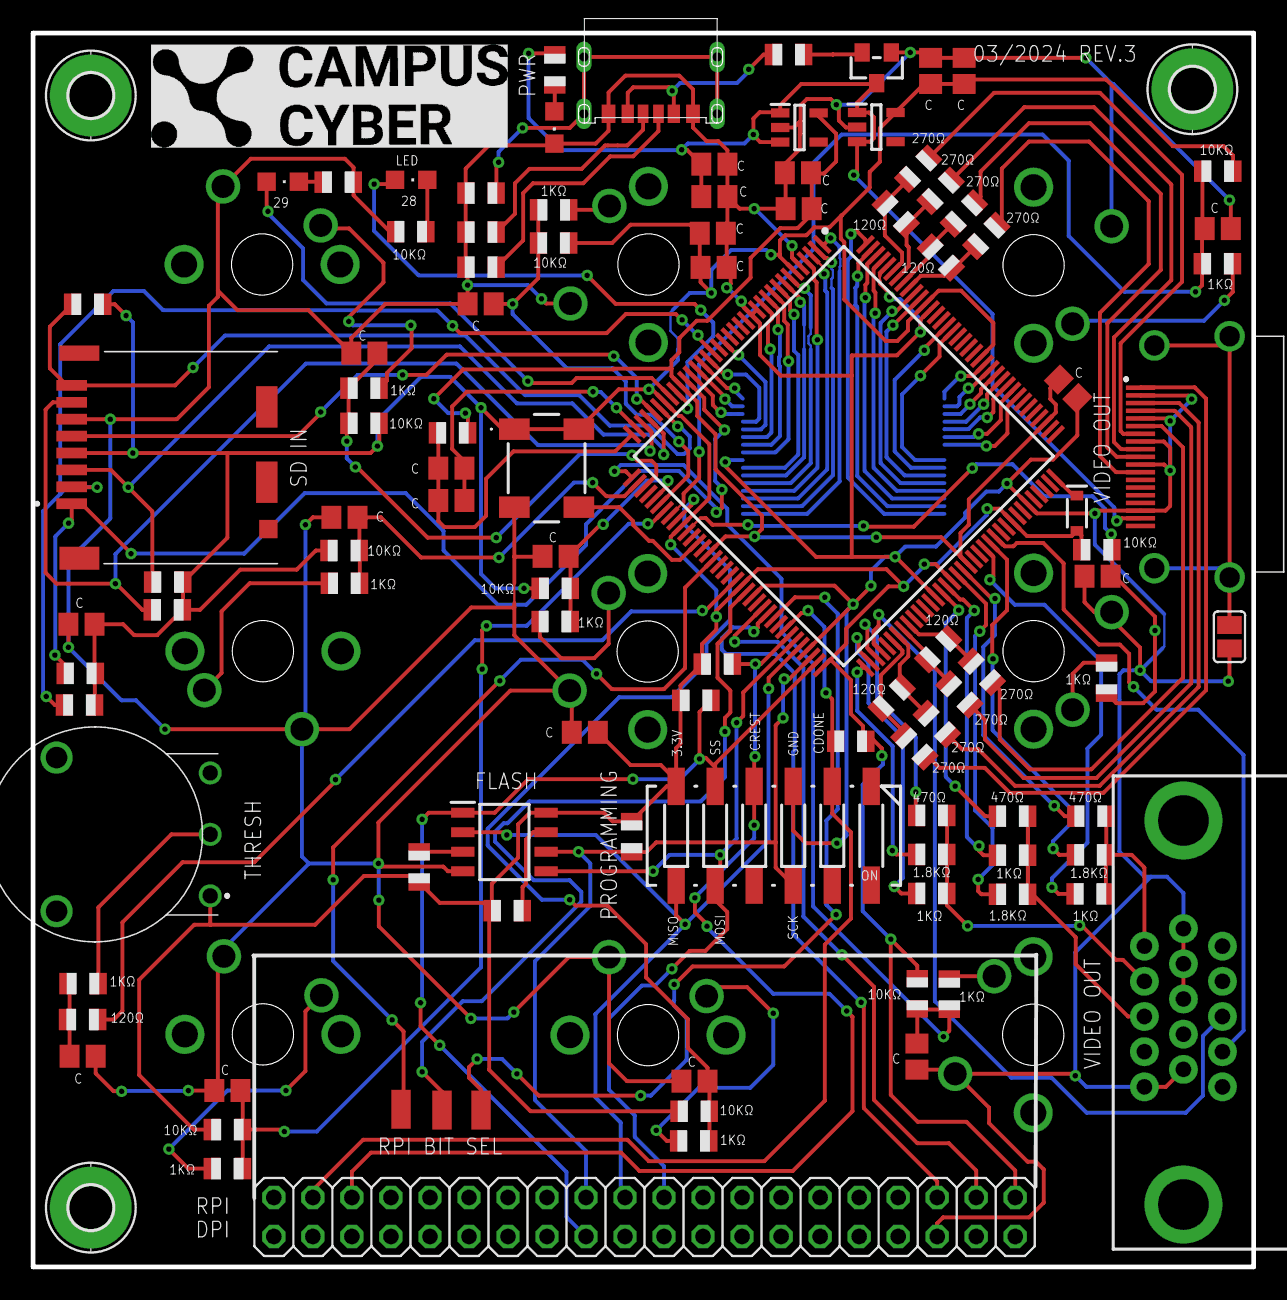
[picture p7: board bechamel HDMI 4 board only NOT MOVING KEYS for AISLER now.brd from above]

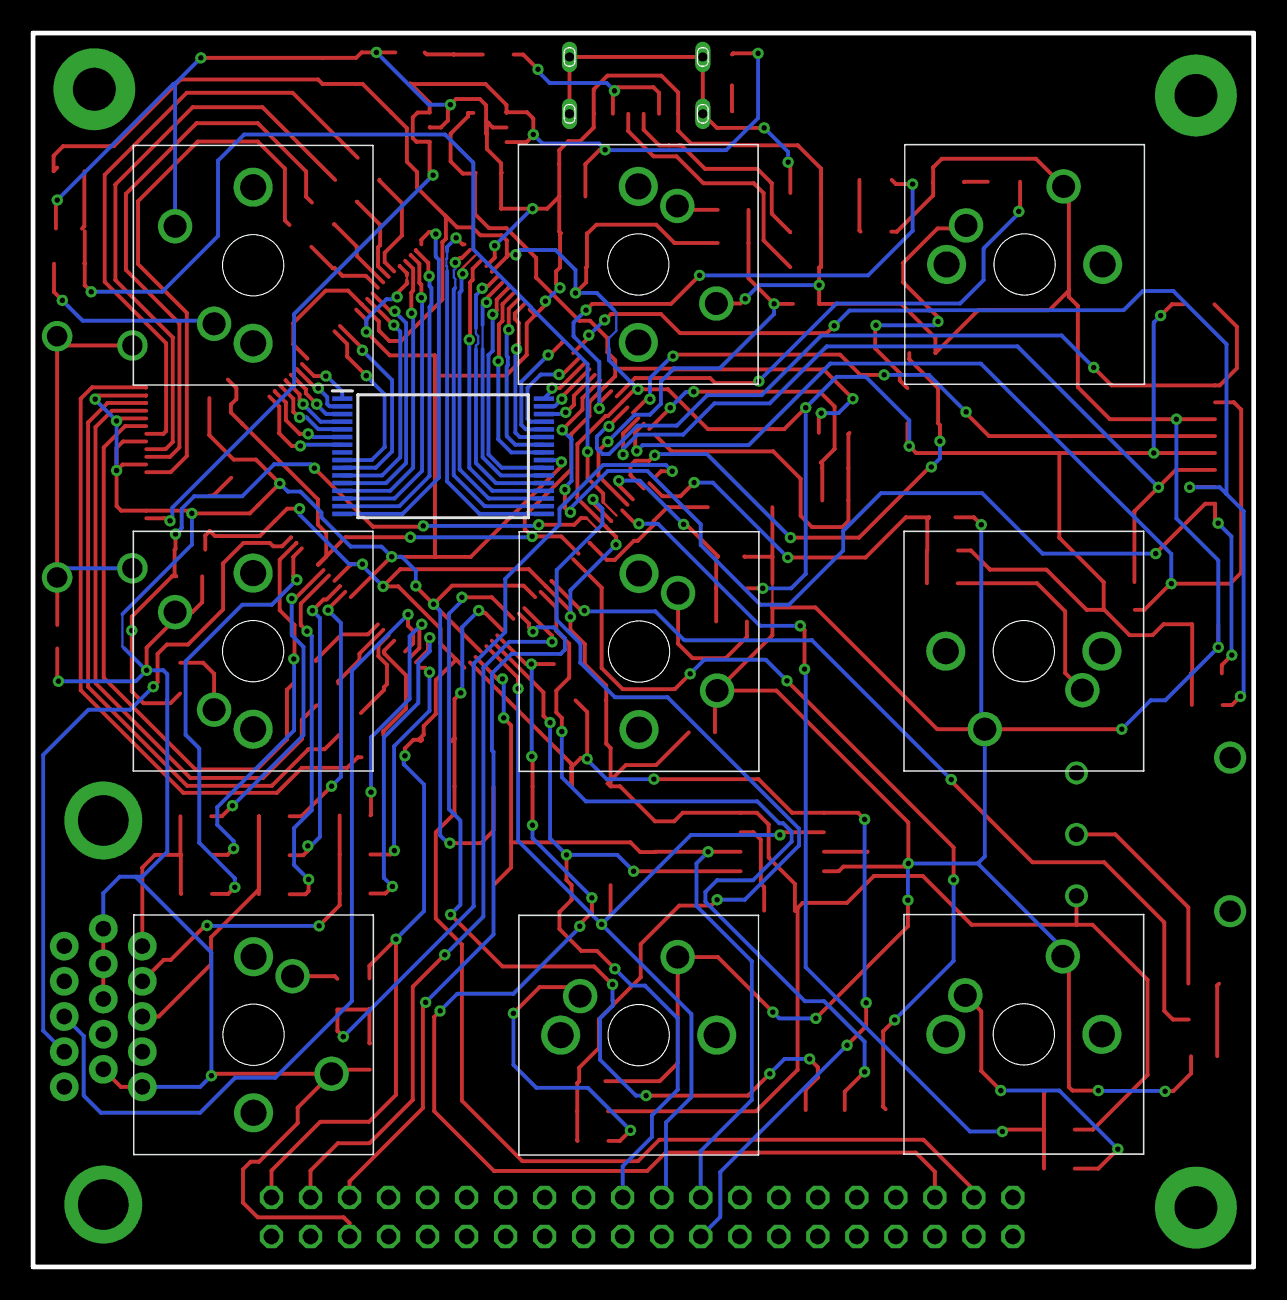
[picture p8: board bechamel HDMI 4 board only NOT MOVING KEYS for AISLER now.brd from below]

Board: 2 copper layers, 79.5 x 80.3 mm, 117 parts (10 on the bottom side), 119 nets.

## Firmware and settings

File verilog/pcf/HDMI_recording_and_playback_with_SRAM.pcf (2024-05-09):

set_io hdmi_p[0] 139 -io_std SB_LVCMOS
set_io hdmi_p[2] 78 -io_std SB_LVCMOS
set_io hdmi_p[1] 80 -io_std SB_LVCMOS
set_io hdmi_p[3] 137 -io_std SB_LVCMOS

set_io hdmi_n[0] 138 -io_std SB_LVCMOS
set_io hdmi_n[2] 79 -io_std SB_LVCMOS
set_io hdmi_n[1] 81 -io_std SB_LVCMOS
set_io hdmi_n[3] 136 -io_std SB_LVCMOS

set_io key[0] 37
set_io key[1] 38
set_io key[2] 39
set_io key[3] 41
set_io key[4] 42
set_io key[5] 43
set_io key[6] 44
set_io key[7] 45
set_io rec 47

set_io SCK 32
set_io CMD 33

set_io LED1 29
set_io LED5 28

set_io reset 66

set_io clk100 49

set_io b_in 63

set_io rpi_pixel_clock 61
set_io rpi_hsync 52
set_io rpi_vsync 58
set_io rpi_DEN 62

set_io v_sync 97 //for vga
set_io h_sync 76 //for vga

set_io io[0] 7
set_io io[1] 8
set_io io[2] 9
set_io io[3] 10
set_io io[4] 11
set_io io[5] 12
set_io io[6] 19
set_io io[7] 22

set_io addr[0] 4
set_io addr[1] 3
set_io addr[2] 2
set_io addr[3] 1
set_io addr[4] 144
set_io addr[5] 143
set_io addr[6] 142
set_io addr[7] 141
set_io addr[8] 120
set_io addr[9] 121
set_io addr[10] 24
set_io addr[11] 122
set_io addr[12] 135
set_io addr[13] 119
set_io addr[14] 134
set_io addr[15] 116
set_io addr[16] 129
set_io addr[17] 128


set_io cs 25
set_io oe 23
set_io we 118

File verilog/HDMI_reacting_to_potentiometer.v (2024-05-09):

/*

From : http://hamsterworks.co.nz/mediawiki/index.php/Cheap_Analogue_Input

For this project the FPGA pin is used as bidirectional pin. To complete an acquisition the pin is set to active low. 
Any charge in the capacitor flows into the FPGA via the 180 ohm resistor until it reaches the 'low' level. 
Then the output is set to high-Z mode, and the capacitor charges from the 3.3 V rail, 
via the 1.8k resistor and the 100k potentiometer, until it reaches 3.3 V.
 While the is Capacitor charges the FPGA counts how many clock cycles it takes for the capacitor to charge, 
 and remembers when the input becomes 'true'. This value then gets output via the seven segment display.
 
 
 SOME CALCULATIONS :


Fastest charging time possible is when the 10K is set at zero. The resistance in that case is just the 1K resistor in series.

The time it takes the cap to charge in this case is is 0.7 x tau = 0.00007 seconds.

I'm using 25MHz clock which takes 1,750 cycles (with a period of 0.00000004 seconds) to count that long.


Slowest charging time possible is when the 10K is set at full. The resistance in that case is 10K + the 1K resistor in series.

The time it takes the cap to charge in this case is is 0.7 x tau = 0.00077 seconds.

I'm using 25MHz clock which takes 19,250 cycles (with a period of 0.00000004 seconds) to count that long.

This means I have a range of time to count between 1,750 and 19,250 cycles.


I need at least a 15 bit counter (2^15 max value of 32,768) to be able to count up to 19,250.

10,500 cycles would make a good threshold as it is between the min and the max. This is equal to 010100100000100 in binary.

*/

`default_nettype none // disable implicit definitions by Verilog
//-----------------------------------------------------------------
// minimalDVID_encoder.vhd : A quick and dirty DVI-D implementation
//
// Author: Mike Field <hamster@snap.net.nz>
//
// DVI-D uses TMDS as the 'on the wire' protocol, where each 8-bit
// value is mapped to one or two 10-bit symbols, depending on how
// many 1s or 0s have been sent. This makes it a DC balanced protocol,
// as a correctly implemented stream will have (almost) an equal
// number of 1s and 0s.
//
// Because of this implementation quite complex. By restricting the
// symbols to a subset of eight symbols, all of which having have
// five ones (and therefore five zeros) this complexity drops away
// leaving a simple implementation. Combined with a DDR register to
// send the symbols the complexity is kept very low.
//-----------------------------------------------------------------

module top(
clk100, key, hdmi_p, hdmi_n, reset, adc
);

inout adc;

input reset;
input clk100;
input [8:0] key;
output [3:0] hdmi_p;
output [3:0] hdmi_n;

// to store values from other modules
wire half_sec;

wire [12:0] random_number_0;
wire [12:0] random_number_1;
wire [12:0] random_number_2;
wire [12:0] random_number_3;
wire [12:0] random_number_4;
wire [12:0] random_number_5;
wire [12:0] random_number_6;
wire [12:0] random_number_7;
wire [12:0] random_number_8;
wire [12:0] random_number_9;
wire [7:0] sine_wave;

// for our bittiness
wire [9:0] bit_or;
assign bit_or = hc[9:0]|vc[9:0];

wire [9:0] bit_xor;
assign bit_xor = hc[9:0]^vc[9:0];

wire [9:0] bit_and;
assign bit_and = hc[9:0]&vc[9:0];

wire [9:0] bit_nand;
assign bit_nand = hc[9:0]& ~vc[9:0];

wire [9:0] bit_xnor;
assign bit_xnor = hc[9:0]^ ~vc[9:0];

reg [9:0] out_bit ;

reg [1:0] count2; //to keep track of the shifts



// For holding the outward bound TMDS symbols in the slow and fast domain
reg [9:0] c0_symbol; reg [9:0] c0_high_speed;
reg [9:0] c1_symbol; reg [9:0] c1_high_speed;
reg [9:0] c2_symbol; reg [9:0] c2_high_speed;
reg [9:0] clk_high_speed;

reg [1:0] c2_output_bits;
reg [1:0] c1_output_bits;
reg [1:0] c0_output_bits;
reg [1:0] clk_output_bits;

wire clk_x5;
reg [2:0] latch_high_speed = 3'b100; // Controlling the transfers into the high speed domain

wire vsync, hsync;
wire [1:0] syncs; // To glue the HSYNC and VSYNC into the control character
assign syncs = {vsync, hsync};

// video structure constants
parameter hpixels = 800; // horizontal pixels per line
parameter vlines = 525; // vertical lines per frame
parameter hpulse = 96; // hsync pulse length
parameter vpulse = 2; // vsync pulse length
parameter hbp = 144; // end of horizontal back porch (96 + 48)
parameter hfp = 784; // beginning of horizontal front porch (800 - 16)
parameter vbp = 35; // end of vertical back porch (2 + 33)
parameter vfp = 515; // beginning of vertical front porch (525 - 10)

// registers for storing the horizontal & vertical counters
reg [9:0] vc;
reg [9:0] hc;
// generate sync pulses (active high)
assign vsync = (vc < vpulse);
assign hsync = (hc < hpulse);


reg [15:0] adc_count= 0; //15 bits to count how long it's taking to charge. 32,768 is the max value. 1 extra MSB bit for just discharging the cap.
reg [14:0] pot_value= 0; //to store cap charge time value

wire adc_in;
reg adc_sample = 1; //first time through we want to sample the cap value


assign adc = (adc_sample) ? 1'bZ : 1'b0;
assign adc_in = adc;

always @(posedge latch_high_speed[2]) begin //25MHz clock

		
	adc_count <= adc_count + 1; // start counting

		if(adc_count>=16'b1000000000000000)begin // once we have rolled over 15 bit counter...

			adc_sample <= 1'b0; // ...discharge cap for a while to restart the process.
		end

		else begin
			
			adc_sample<=1'b1; //put cap pin in high 'Z'

			if(adc_in==1'b1) begin // if cap charged...

				pot_value[14:0]<=adc_count[14:0]; //store this value in pot 

			end


		end

end

always @(posedge clk_x5) begin
//-------------------------------------------------------------
// Now take the 10-bit words and take it into the high-speed
// clock domain once every five cycles.
//
// Then send out two bits every clock cycle using DDR output
// registers.
//-------------------------------------------------------------
c0_output_bits <= c0_high_speed[1:0];
c1_output_bits <= c1_high_speed[1:0];
c2_output_bits <= c2_high_speed[1:0];
clk_output_bits <= clk_high_speed[1:0];
if (latch_high_speed[2]) begin // pixel clock 25MHz
c0_high_speed <= c0_symbol;
c1_high_speed <= c1_symbol;
c2_high_speed <= c2_symbol;
clk_high_speed <= 10'b0000011111;
latch_high_speed <= 3'b000;
if (hc < hpixels)
hc <= hc + 1;
else
begin
hc <= 0;
if (vc < vlines)
vc <= vc + 1;
else
vc <= 0;
end
end
else begin
c0_high_speed <= {2'b00, c0_high_speed[9:2]};
c1_high_speed <= {2'b00, c1_high_speed[9:2]};
c2_high_speed <= {2'b00, c2_high_speed[9:2]};
clk_high_speed <= {2'b00, clk_high_speed[9:2]};
latch_high_speed <= latch_high_speed + 1'b1;
end
end

always @(posedge latch_high_speed[2]) begin 

      case(count2)
	  
        2'b00: out_bit = bit_or;  
        2'b01: out_bit = bit_xor;
        2'b10: out_bit = bit_and;
        2'b11: out_bit = bit_nand;			

       default: out_bit = bit_xnor;
       endcase
	   count2=count2+1;
end
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

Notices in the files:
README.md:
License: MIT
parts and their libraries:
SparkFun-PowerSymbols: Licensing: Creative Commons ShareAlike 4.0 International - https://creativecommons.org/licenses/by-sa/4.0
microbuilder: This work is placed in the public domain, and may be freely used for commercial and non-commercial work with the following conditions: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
